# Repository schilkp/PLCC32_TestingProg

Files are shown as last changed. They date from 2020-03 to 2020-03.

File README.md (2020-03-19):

# PLCC_TestingProg
### Philipp Schilk

A board for programming/testing the SST39SF040 flash IC. 
It includes a PLCC32 Socket, breakouts of the Data, Address and Control Lines,
and optional shift registers to drive the address lines during programming.

Furthermore, if nothing but the PLCC32 socket is fitted, it may serve as a direct
breakout. 

Designed for the SST39SF040, but also usable with all other chips in the family
(F020, F010). Could be compatible with many other flash chips with similar layout. 

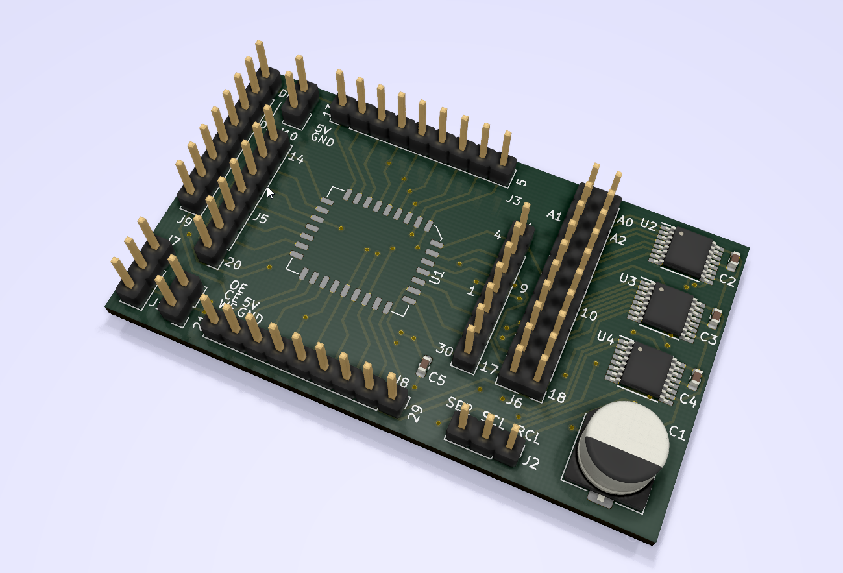
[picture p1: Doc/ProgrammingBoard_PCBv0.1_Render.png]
PCB v0.1 Render


## Overview

**Doc:**
	Documentation

**Gerber:**
	Gerber Files for PCB Manufacture

**KiCad:**
    KiCad Project Files (Schematic and PCB).
    Download KiCad at [kicad-pcb.org](https://kicad-pcb.org/download/).

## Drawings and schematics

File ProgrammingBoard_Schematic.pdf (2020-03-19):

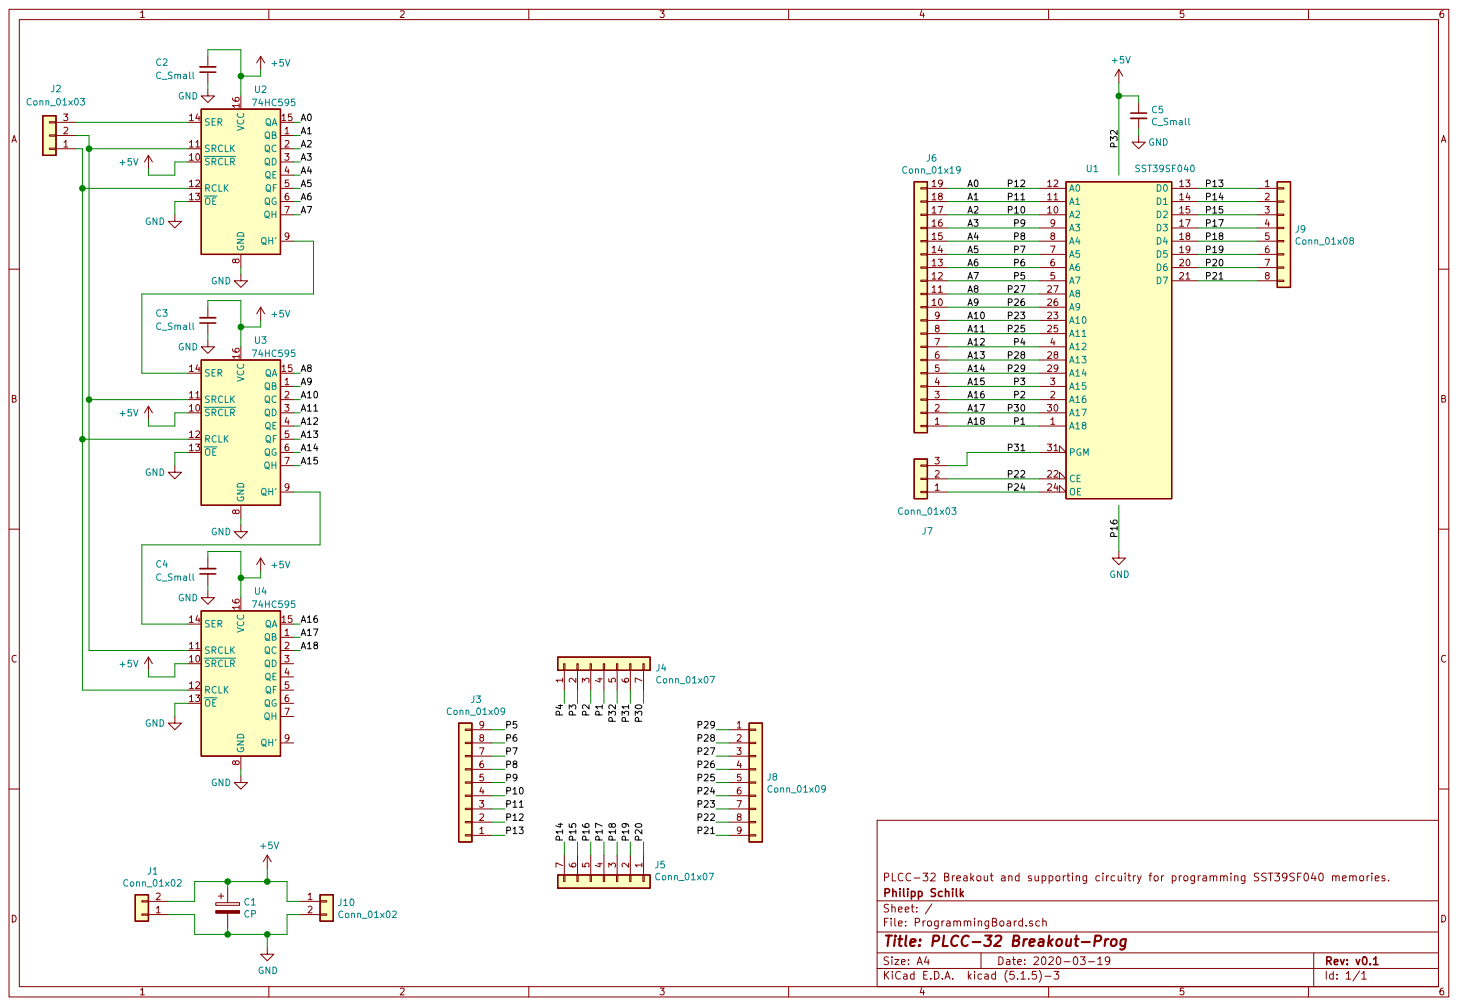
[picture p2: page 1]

File: ProgrammingBoard.sch Sheet: / Philipp Schilk

Id: 1/1 Title: PLCC-32 Breakout-Prog

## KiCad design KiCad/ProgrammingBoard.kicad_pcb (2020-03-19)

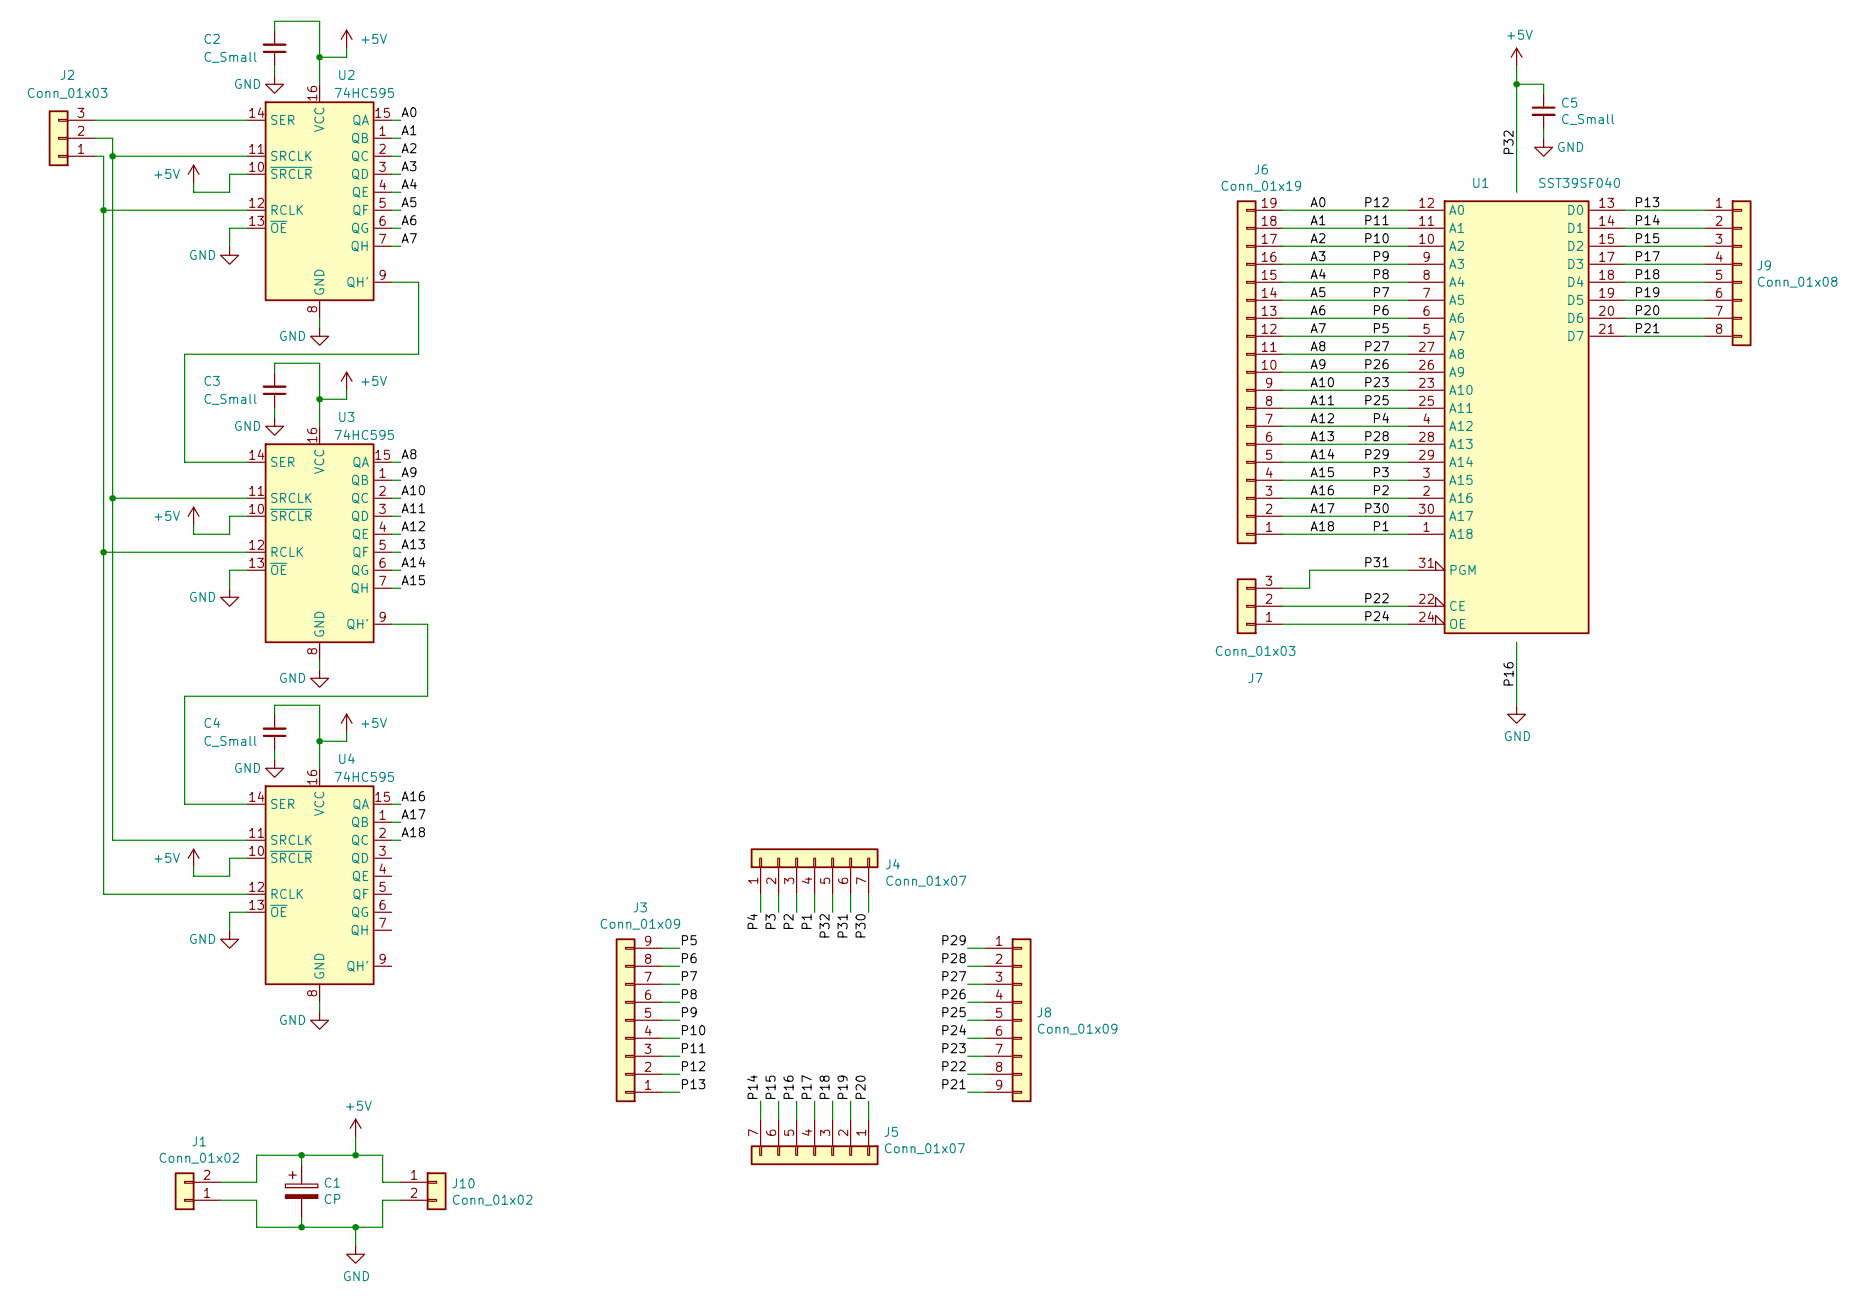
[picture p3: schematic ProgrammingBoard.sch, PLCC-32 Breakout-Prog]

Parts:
C1: CP; CP_Elec_8x6.5
C2, C3, C4, C5: C_Small; C_0603_1608Metric
J1, J10: Conn_01x02; PinHeader_1x02_P2.54mm_Vertical
J2, J7: Conn_01x03; PinHeader_1x03_P2.54mm_Vertical
J3, J8: Conn_01x09; PinHeader_1x09_P2.54mm_Vertical
J4, J5: Conn_01x07; PinHeader_1x07_P2.54mm_Vertical
J6: Conn_01x19; PinHeader_2x10_P2.54mm_Vertical
J9: Conn_01x08; PinHeader_1x08_P2.54mm_Vertical
U1: SST39SF040; PLCC-32_11.4x14.0mm_P1.27mm
U2, U3, U4: 74HC595; TSSOP-16_4.4x5mm_P0.65mm

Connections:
+5V: C1.1, C2.2, C3.2, C4.2, C5.1, J1.2, J4.5, J10.1, U1.32 (VCC), U2.10 (~SRCLR), U2.16 (VCC), U3.10 (~SRCLR), U3.16 (VCC), U4.10 (~SRCLR), U4.16 (VCC)
/A0: J3.2, J6.19, U1.12 (A0), U2.15 (QA)
/A1: J3.3, J6.18, U1.11 (A1), U2.1 (QB)
/A2: J3.4, J6.17, U1.10 (A2), U2.2 (QC)
/A3: J3.5, J6.16, U1.9 (A3), U2.3 (QD)
/A4: J3.6, J6.15, U1.8 (A4), U2.4 (QE)
/A5: J3.7, J6.14, U1.7 (A5), U2.5 (QF)
/A6: J3.8, J6.13, U1.6 (A6), U2.6 (QG)
/A7: J3.9, J6.12, U1.5 (A7), U2.7 (QH)
/A8: J6.11, J8.3, U1.27 (A8), U3.15 (QA)
/A9: J6.10, J8.4, U1.26 (A9), U3.1 (QB)
/A10: J6.9, J8.7, U1.23 (A10), U3.2 (QC)
/A11: J6.8, J8.5, U1.25 (A11), U3.3 (QD)
/A12: J4.1, J6.7, U1.4 (A12), U3.4 (QE)
/A13: J6.6, J8.2, U1.28 (A13), U3.5 (QF)
/A14: J6.5, J8.1, U1.29 (A14), U3.6 (QG)
/A15: J4.2, J6.4, U1.3 (A15), U3.7 (QH)
/A16: J4.3, J6.3, U1.2 (A16), U4.15 (QA)
/A17: J4.7, J6.2, U1.30 (A17), U4.1 (QB)
/A18: J4.4, J6.1, U1.1 (A18), U4.2 (QC)
/P13: J3.1, J9.1, U1.13 (D0)
/P14: J5.7, J9.2, U1.14 (D1)
/P15: J5.6, J9.3, U1.15 (D2)
/P17: J5.4, J9.4, U1.17 (D3)
/P18: J5.3, J9.5, U1.18 (D4)
/P19: J5.2, J9.6, U1.19 (D5)
/P20: J5.1, J9.7, U1.20 (D6)
/P21: J8.9, J9.8, U1.21 (D7)
/P22: J7.2, J8.8, U1.22 (CE)
/P24: J7.1, J8.6, U1.24 (OE)
/P31: J4.6, J7.3, U1.31 (PGM)
GND: C1.2, C2.1, C3.1, C4.1, C5.2, J1.1, J5.5, J10.2, U1.16 (GND), U2.8 (GND), U2.13 (~OE), U3.8 (GND), U3.13 (~OE), U4.8 (GND), U4.13 (~OE)
unnamed: J2.1, U2.12 (RCLK), U3.12 (RCLK), U4.12 (RCLK)
unnamed: J2.2, U2.11 (SRCLK), U3.11 (SRCLK), U4.11 (SRCLK)
unnamed: J2.3, U2.14 (SER)
unnamed: U2.9 (QH'), U3.14 (SER)
unnamed: U3.9 (QH'), U4.14 (SER)

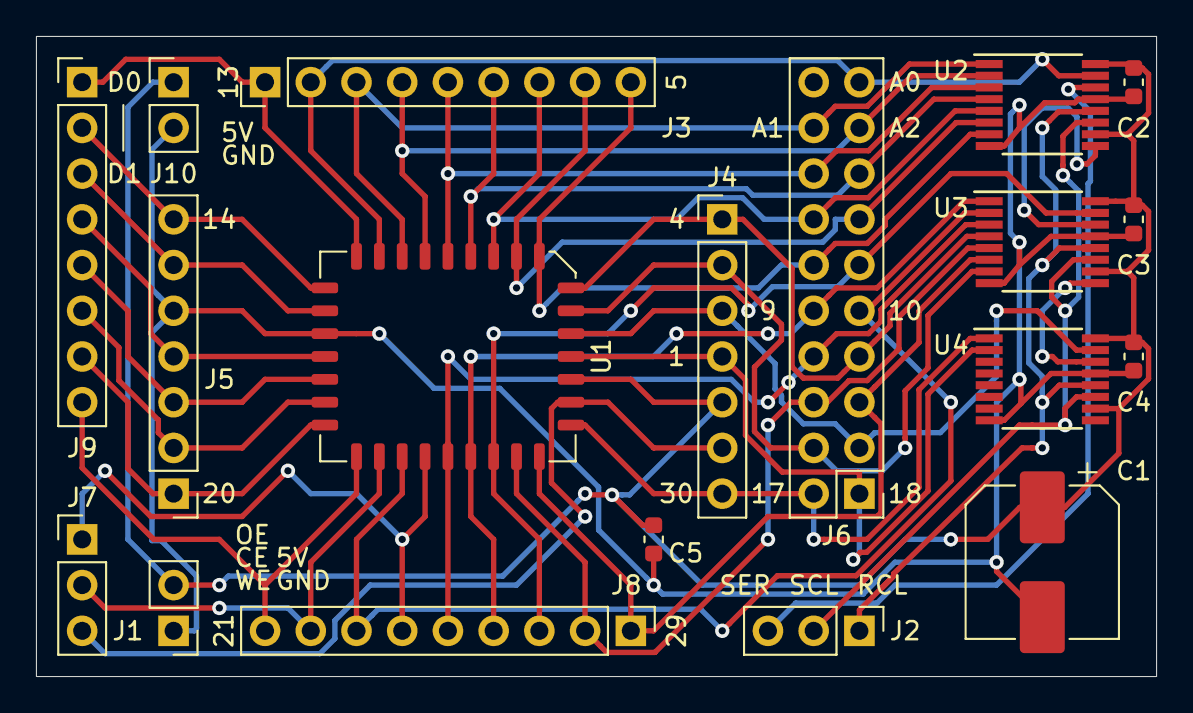
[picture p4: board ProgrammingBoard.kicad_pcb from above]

Board: 2 copper layers, 62.2 x 35.6 mm, 19 parts (0 on the bottom side), 37 nets.

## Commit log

2020-02-13 v0.0 - Initial Commit
    State of project at production of PCB v0.0
    [ProgrammingBoard-B_Cu.gbr, ProgrammingBoard-B_Mask.gbr, ProgrammingBoard-B_Paste.gbr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]
2020-02-14 Added Render of PCB v0.0
2020-03-19 Moved silkscreen covered by PLCC-32 Socket
    [ProgrammingBoard-B_Cu.gbr, ProgrammingBoard-B_Mask.gbr, ProgrammingBoard-B_Paste.gbr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]
